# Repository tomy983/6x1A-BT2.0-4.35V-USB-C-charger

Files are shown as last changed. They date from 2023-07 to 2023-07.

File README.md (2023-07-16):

# 6x1A-BT2.0-4.35V-USB-C-charger
6 1S lipo cells charger with BT2.0 connectors - 1A charge current (each) - USB-C PD powered

Untested project.

The way it should work is:

12V via USB-C PD is requested. If the supply will comply 12V Vbus goes trough an 8A buck conveter to deliver 5V to each of 6 individual 4.35V 1A charger IC.

A green LED indicates 12V rail from PD present.

Green and red leds near each BT2.0 connector indicates charging status.



The BOM is made with JLCPCB component list in mind. Current production quote is 39€ for 2 pcs.

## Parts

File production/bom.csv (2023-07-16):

Designator | Footprint | Quantity | Value | LCSC Part #
C1, C10, C11, C12, C2, C3, C4, C5, C6, C7, C8, C9 | 0603 | 12 | 10u
C13 | 0603 | 1 | 1u | CL10A105KB8NNNC
Cbst1 | 1206 | 1 | 100n | GRM31C5C1H104JA01K
Cff1 | 0402 | 1 | 220p | GRM1555C1H221JA01J
Cihf_ch1, Cihf_ch2 | 0603 | 2 | 100n | GRM188R71H104KA93D
Cin1 | 1210 | 1 | 10u | GRM32ER71J106KA12L
Cout1 | CP_Elec_6.3x5.9 | 1 | 180u | 16SVPF180M
Coutx1 | 0805 | 1 | 22u | GRM21BR61A226ME44L
Creg1 | 0603 | 1 | 4.7u | CC0603KRX7R9BB822
Css1 | 0603 | 1 | 10n | CC0603KRX7R9BB822
D1, D10, D12, D13, D4, D6, D8 | 0603 | 7 | GREEN | 19-217/GHC-YR1S2/3T
D11, D2, D3, D5, D7, D9 | 0603 | 6 | RED | 19-213/R6W-BP2Q2B/3T
J1, J2, J3, J4, J5, J6 | BT2.0 | 6 | Conn_01x02 | betafpv BT2.0 MALE
J7 | USB_C_Receptacle_G-Switch_GT-USB-7010ASV | 1 | USB_C_CONN | GT-USB-7010ASV
L1 | L_Chilisin_BMRF00101040 | 1 | 1.6uH | YSPI1040-1R5M
R1, R14, R20, R26, R32, R8 | 0603 | 6 | 1
R10, R100, R13, R15, R16, R19, R2, R21, R22, R25, R27, R28, R3, R31, R33, R34, R4, R44, R7, R9 | 0603 | 20 | 1K
R101, Rfbb1, Rpg1 | 0603 | 3 | 10K
R102 | 0603 | 1 | 24K
Rfbt1 | 0603 | 1 | 73.2K
Rmh1 | 0603 | 1 | 121K
Rml1 | 0603 | 1 | 20K
U1, U2, U3, U4, U5, U6 | DFN-8-1EP_2x2mm_P0.5mm_EP0.9x1.6mm | 6 | LGS4056HDA-4.35 | LGS4056HDA-4.35
U7 | ESSOP10 | 1 | CH224K | CH224K
U8 | Texas_RNN0018A | 1 | TPS568215RNN | TPS568215RNN

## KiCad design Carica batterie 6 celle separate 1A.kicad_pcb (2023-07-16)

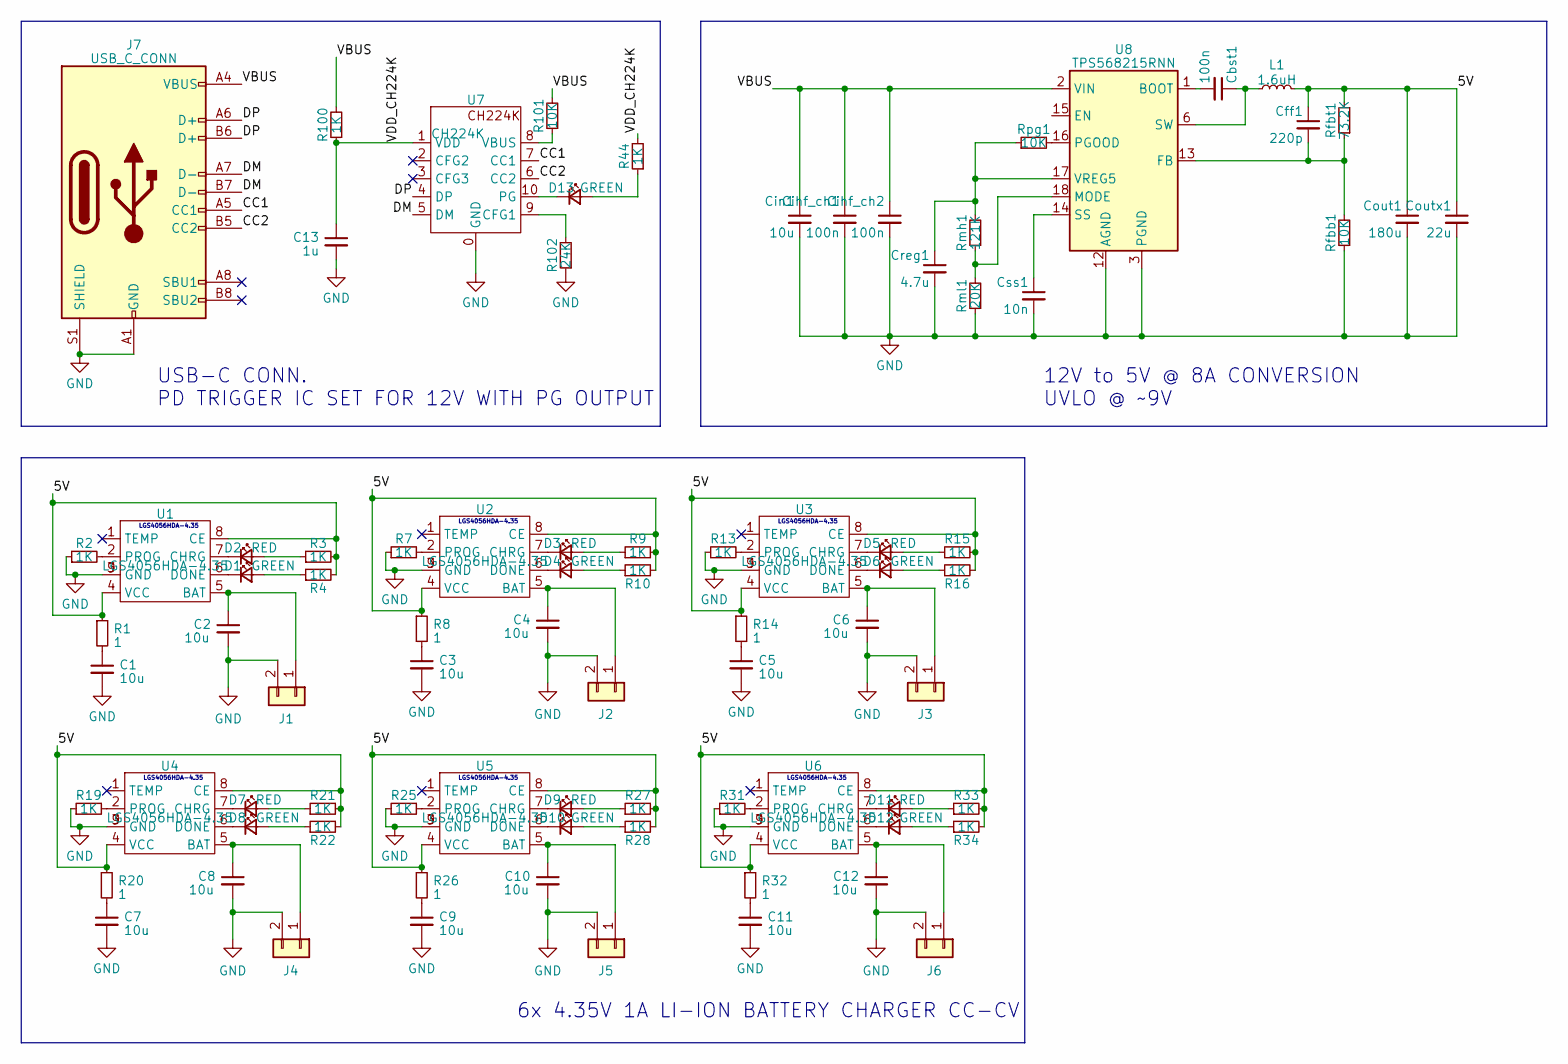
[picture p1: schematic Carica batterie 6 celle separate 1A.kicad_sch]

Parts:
C1, C2, C3, C4, C5, C6, C7, C8, C9, C10, C11, C12: 10u; C_0603_1608Metric
C13: 1u; C_0603_1608Metric; MPN CL10A105KB8NNNC
Cbst1: 100n; C_1206_3216Metric; MPN GRM31C5C1H104JA01K
Cff1: 220p; C_0402_1005Metric; MPN GRM1555C1H221JA01J
Cihf_ch1, Cihf_ch2: 100n; C_0603_1608Metric; MPN GRM188R71H104KA93D
Cin1: 10u; C_1210_3225Metric; MPN GRM32ER71J106KA12L
Cout1: 180u; CP_Elec_6.3x5.9; MPN 16SVPF180M
Coutx1: 22u; C_0805_2012Metric; MPN GRM21BR61A226ME44L
Creg1: 4.7u; C_0603_1608Metric; MPN CC0603KRX7R9BB822
Css1: 10n; C_0603_1608Metric; MPN CC0603KRX7R9BB822
D1, D4, D6, D8, D10, D12, D13: GREEN; LED_0603_1608Metric; MPN 19-217/GHC-YR1S2/3T
D2, D3, D5, D7, D9, D11: RED; LED_0603_1608Metric; MPN 19-213/R6W-BP2Q2B/3T
J1, J2, J3, J4, J5, J6: Conn_01x02; BT2.0; MPN betafpv BT2.0 MALE
J7: USB_C_CONN; USB_C_Receptacle_G-Switch_GT-USB-7010ASV; MPN GT-USB-7010ASV
L1: 1.6uH; L_Chilisin_BMRF00101040; MPN YSPI1040-1R5M
R1, R8, R14, R20, R26, R32: 1; R_0603_1608Metric
R2, R3, R4, R7, R9, R10, R13, R15, R16, R19, R21, R22, R25, R27, R28, R31, R33, R34, R44, R100: 1K; R_0603_1608Metric
R101: 10K; R_0603_1608Metric
R102: 24K; R_0603_1608Metric
Rfbb1: 10K; R_0603_1608Metric
Rfbt1: 73.2K; R_0603_1608Metric
Rmh1: 121K; R_0603_1608Metric
Rml1: 20K; R_0603_1608Metric
Rpg1: 10K; R_0603_1608Metric
U1, U2, U3, U4, U5, U6: LGS4056HDA-4.35; DFN-8-1EP_2x2mm_P0.5mm_EP0.9x1.6mm; MPN LGS4056HDA-4.35
U7: CH224K; ESSOP10; MPN CH224K
U8: TPS568215RNN; Texas_RNN0018A; MPN TPS568215RNN

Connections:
/5V: Cff1.1, Cout1.1, Coutx1.1, L1.2, R1.1, R3.2, R4.2, R8.1, R9.2, R10.2, R14.1, R15.2, R16.2, R20.1, R21.2, R22.2, R26.1, R27.2, R28.2, R32.1, R33.2, R34.2, Rfbt1.2, U1.4 (VCC), U1.8 (CE), U2.4 (VCC), U2.8 (CE), U3.4 (VCC), U3.8 (CE), U4.4 (VCC), U4.8 (CE), U5.4 (VCC), U5.8 (CE), U6.4 (VCC), U6.8 (CE)
/CC1: J7.A5 (CC1), U7.7 (CC1)
/CC2: J7.B5 (CC2), U7.6 (CC2)
/DM: J7.A7 (D-), J7.B7 (D-), U7.5 (DM)
/DP: J7.A6 (D+), J7.B6 (D+), U7.4 (DP)
/VBUS: Cihf_ch1.1, Cihf_ch2.1, Cin1.1, J7.A4 (VBUS), J7.A9 (VBUS), J7.B4 (VBUS), J7.B9 (VBUS), R100.2, R101.2, U8.2 (VIN), U8.11 (VIN)
/VDD_CH224K: C13.1, R44.2, R100.1, U7.1 (VDD)
GND: C1.2, C2.2, C3.2, C4.2, C5.2, C6.2, C7.2, C8.2, C9.2, C10.2, C11.2, C12.2, C13.2, Cihf_ch1.2, Cihf_ch2.2, Cin1.2, Cout1.2, Coutx1.2, Creg1.2, Css1.2, J1.2, J2.2, J3.2, J4.2, J5.2, J6.2, J7.A1 (GND), J7.A12 (GND), J7.B1 (GND), J7.B12 (GND), J7.S1 (SHIELD), R2.1, R7.1, R13.1, R19.1, R25.1, R31.1, R102.1, Rfbb1.1, Rml1.1, U1.3 (GND), U1.9 (GND), U2.3 (GND), U2.9 (GND), U3.3 (GND), U3.9 (GND), U4.3 (GND), U4.9 (GND), U5.3 (GND), U5.9 (GND), U6.3 (GND), U6.9 (GND), U7.0 (GND), U8.3 (PGND), U8.4 (PGND), U8.5 (PGND), U8.8 (PGND), U8.9 (PGND), U8.10 (PGND), U8.12 (AGND)
unnamed: C1.1, R1.2
unnamed: C3.1, R8.2
unnamed: C5.1, R14.2
unnamed: C7.1, R20.2
unnamed: C9.1, R26.2
unnamed: C11.1, R32.2
unnamed: Cbst1.1, L1.1, U8.6 (SW), U8.7 (SW)
unnamed: D1.2 (A), R4.1
unnamed: D1.1 (K), U1.6 (DONE)
unnamed: D2.2 (A), R3.1
unnamed: D2.1 (K), U1.7 (CHRG)
unnamed: D3.2 (A), R9.1
unnamed: D3.1 (K), U2.7 (CHRG)
unnamed: D4.2 (A), R10.1
unnamed: D4.1 (K), U2.6 (DONE)
unnamed: D5.2 (A), R15.1
unnamed: D5.1 (K), U3.7 (CHRG)
unnamed: D6.2 (A), R16.1
unnamed: D6.1 (K), U3.6 (DONE)
unnamed: D7.2 (A), R21.1
unnamed: D7.1 (K), U4.7 (CHRG)
unnamed: D8.2 (A), R22.1
unnamed: D8.1 (K), U4.6 (DONE)
unnamed: D9.2 (A), R27.1
unnamed: D9.1 (K), U5.7 (CHRG)
unnamed: D10.2 (A), R28.1
unnamed: D10.1 (K), U5.6 (DONE)
unnamed: D11.2 (A), R33.1
unnamed: D11.1 (K), U6.7 (CHRG)
unnamed: D12.2 (A), R34.1
unnamed: D12.1 (K), U6.6 (DONE)
unnamed: D13.2 (A), R44.1
unnamed: D13.1 (K), U7.10 (PG)
unnamed: C2.1, J1.1, U1.5 (BAT)
unnamed: C4.1, J2.1, U2.5 (BAT)
unnamed: C6.1, J3.1, U3.5 (BAT)
unnamed: C8.1, J4.1, U4.5 (BAT)
unnamed: C10.1, J5.1, U5.5 (BAT)
unnamed: C12.1, J6.1, U6.5 (BAT)
unnamed: R2.2, U1.2 (PROG)
unnamed: R7.2, U2.2 (PROG)
unnamed: R13.2, U3.2 (PROG)
unnamed: R19.2, U4.2 (PROG)
unnamed: R25.2, U5.2 (PROG)
unnamed: R31.2, U6.2 (PROG)
unnamed: R102.2, U7.9 (CFG1)
unnamed: R101.1, U7.8 (VBUS)
unnamed: Cbst1.2, U8.1 (BOOT)
unnamed: Cff1.2, Rfbb1.2, Rfbt1.1, U8.13 (FB)
unnamed: Rmh1.1, Rml1.2, U8.18 (MODE)
unnamed: Rpg1.2, U8.16 (PGOOD)
unnamed: Css1.1, U8.14 (SS)
unnamed: Creg1.1, Rmh1.2, Rpg1.1, U8.17 (VREG5)

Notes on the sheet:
LGS4056HDA-4.35
6x 4.35V 1A LI-ION BATTERY CHARGER CC-CV
USB-C CONN. PD TRIGGER IC SET FOR 12V WITH PG OUTPUT
12V to 5V @ 8A CONVERSION UVLO @ ~9V

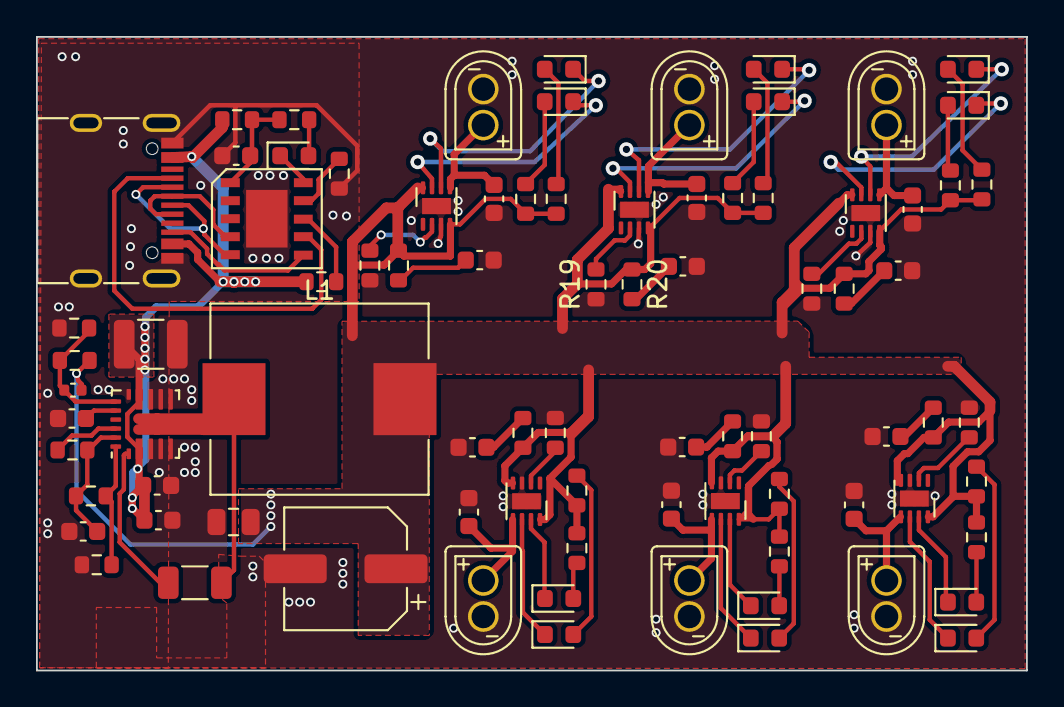
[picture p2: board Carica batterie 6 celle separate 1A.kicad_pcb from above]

Board: 2 copper layers, 55.0 x 35.2 mm, 84 parts (0 on the bottom side), 61 nets.
